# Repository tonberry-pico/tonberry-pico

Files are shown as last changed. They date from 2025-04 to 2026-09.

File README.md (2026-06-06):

# TonBERRY pico

Von [TonUINO](https://www.voss.earth/tonuino/) inspiriert, auf einer moderneren Platform für
zusätzliches Features: WLAN und Bluetooth zum Managen der Audiodateien per Handy-App oder Webseite -
kein Ausbau der SD-Karte mehr nötig. Aus Sicht des Hörers bleibt die Funktionalität aber die selbe -
durch einfaches Auflegen einer RFID-Karte (oder einer Figur mit RFID-Chip) und wenige Tasten zur
Lautstärkeregelung kann das Gerät kinderleicht bedient werden.

Dabei soll der Geist des Ursprungsprojekts, dass es ein "einfach" zu bastelndes Projekt auch für
Elektronik- und Programmier-Unerfahrene ist erhalten bleiben.  Deswegen:
 - Zusammenbau aus fertigen Modulen, die mittels 2.54mm-Raster Sockel/Steckleisten zusammengesetzt
   werden - keine SMD-Lötarbeiten
 - Die Software ist größtenteils (bis auf kritische Module wie z.B. den MP3-Dekoder) in MicroPython
   geschrieben, sodass Anpassungen auch ohne weitergehende Programmierkenntnisse möglich sind
 - Die Kombination aus Raspberry Pi Pico W und sonstigen nötigen Modulen sollte nicht nennenswert
   teurer sein als die Arduino-Module des TonUNIO.

## Anleitung

[Aufbau- und Bedienungsanleitung](https://tonberry-pico.github.io/tonberry-pico/doc/MANUAL.de.html)

### Benötigte Hardware

| Bezeichnung | Berrybase- oder Reichelt-Link |
| --- | --- |
| RFID-RC522 | <https://www.berrybase.de/rfid-lesegeraet-mit-spi-schnittstelle-inkl.-karte-dongle> oder andere RC522 Module (ggf. Pinout beachten) |
| SparkFun microSD Transflash Breakout | [~~https://www.berrybase.de/sparkfun-microsd-transflash-breakout~~](https://www.berrybase.de/sparkfun-microsd-transflash-breakout) Leider nicht mehr verfügbar. [Hier](https://git.ka.blankertz.org/TonBERRY/sparkfun_microSD_Transflash_Breakout) ist das Layout in EAGLE und KiCad zum nachmachen lassen. |
| SparkFun MAX98357A | <https://www.berrybase.de/sparkfun-i2s-audio-breakout-max98357a> oder <https://www.berrybase.de/adafruit-i2s-3w-class-d-verstaerker-breakout-max98357a> oder <https://www.amazon.de/dp/B0F21T7Q3P> |
| Raspberry Pi Pico W | <https://www.berrybase.de/raspberry-pi-pico-w-rp2040-wlan-mikrocontroller-board> |
| Adafruit bq25185 Ladegerät/Spannungswandler für Akkus ab 500mAh, JST PH-2 Pin, USB/DC/Solar, 5V, 1A | <ul><li><https://www.berrybase.de/adafruit-bq25185-ladegeraet-spannungswandler-fuer-akkus-ab-500mah-jst-ph-2-pin-usb-dc-solar-5v-1a></li><li><https://www.kiwi-electronics.com/en/adafruit-bq25185-usb-dc-solar-charger-with-5v-boost-board-20429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></li></ul> |
| Übrige Komponenten | <https://www.reichelt.de/my/2314794> |

### Software

Die Software ist [auf Github](https://github.com/tonberry-pico/tonberry-pico) zu finden.

### Gehäuse

Test-Aufbau für Entwickler: <https://www.printables.com/model/1745596-tonberry-pico-test-rig>

## Design

[Überlegungen zum Design](https://github.com/tonberry-pico/tonberry-pico/wiki/Design) gibt's im Wiki.

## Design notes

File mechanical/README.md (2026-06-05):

# Tonberry pico cases

## Test rig

The test rig consists of three parts:

The front plate holds the speaker. The mounting holes are for either a Visaton R10 S (or similiar)
speaker, or a small mono speaker https://www.adafruit.com/product/3351 .

The base plate is available in two versions: For the Rev. 1 PCB (the larger PCB with the buttons
mounted directly on the PCB, deprecated), and the Rev. 1.2 PCB plus an optional button board.

The RC522 holder clips onto the top and holds the RC522 NFC reader so that a tag or card can easily
be placed on it.

Besides the 3D printed parts, you need some hardware:

* M3x5x4 heat sink inserts: 8 for the Rev.1 PCB or if you aren't using a button board with the Rev. 1.2, or 12 for a Rev. 1.2 PCB plus button board. 
* M3x6 BHCS (button head) screws to mount the PCB(s): 4 or 8
* M3x8 countersunk screws: 4, to mount the front plate to the base
* M3x12 countersunk screws + M3 nuts: 4, to mount the RC522 to the holder
* For the Visaton speaker: 4x M4x8 countersunk screws + 4x M4 nuts
* For the ADA3351 speaker: 4x M3x? countersunk screws + 4x M3 nuts

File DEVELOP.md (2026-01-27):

# Developer notes

## How to setup python environment for mypy and pytest

```bash
cd software
python -m venv test-venv
. test-venv/bin/activate
pip install -r tests/requirements.txt
pip install -U micropython-rp2-pico_w-stubs --target typings
```

## 'database' schema for btree db

### Playlist storage

The playlist data is stored in the btree database in a hierarchical schema. The hierarchy levels are
separated by the '/' character.  Currently, the schema is as follows: The top level for a playlist
is the 'tag' id encoded as a hexadecimal string. Beneath this, the 'playlist' key contains the
elements in the playlist. The keys used for the playlist entries must be decimal integers,
left-padded with zeros so their length is 5 (e.g. format `{:05}`).

#### Playlist modes

The 'playlistshuffle' key located under the 'tag' key can be 'no' or 'yes' and specifies whether the
playlist is in shuffle mode. Should this key be absent the default value is 'no'.

The 'playlistpersist' key located under the 'tag' key can be 'no', 'track' or 'offset'. Should this
key be absent the default value is 'track'.

 * When it is 'no', the playlist position is not saved when playback stops. If shuffle mode is
   active, the shuffle random seed is also not saved.
 * When it is 'track', the currently playing track is saved when playback stops. If shuffle mode is
   active, the shuffle random seed is also saved. Should playback reach the last track (in shuffle
   mode: the last track in the permutated order), the saved position is reset and playback is
   stopped. The next time the playlist is started it will start from the first track and with a new
   shuffle seed if applicable.
 * When it is 'offset', the operation is basically the same as in 'track' mode. The difference is
   that the offset in the currently playing track is also saved and playback will resume at that
   position.

The 'playlistpos' key located under the 'tag' key stores the key of the current playlist
entry. The 'playlistshuffleseed' key stores the random seed used to shuffle the playlist.
The 'playlistposoffset' key stores the offset in the current playlist entry.

#### Example

For example, a playlist with two entries 'a.mp3' and 'b.mp3' for a tag with the id '00aa11bb22'
would be stored in the following key/value pairs in the btree db:

 * 00aa11bb22/playlist/00000: a.mp3
 * 00aa11bb22/playlist/00001: b.mp3
 * 00aa11bb22/playlistpos: 00000

## Notes for UI development with chromium

Features for the web interface are best prototyped in a browser directly. By using the built-in developmer tools and
and their "override" feature, the web contents are replaced by a locally stored copy, which can be used to directly
test the modifications without going all the way through the build and flash process.

However, modern browsers may restrict or even completely forbid the execution of dynamic content like JavaScript, if
the content is stored on the local machine and/or the content is accessed using http. In such a case, chromium issues
an error message similar to the following one:

> Access to fetch at 'http://192.168.4.1/api/v1/audiofiles' from origin 'http://192.168.4.1' has been blocked by CORS
> policy: The request client is not a secure context and the resource is in more-private address space `local`.

To mitigate this, chromium offers two flags that need modification:
- 'chrome://flags/#local-network-access-check' must be `Disabled`
- 'chrome://flags/#unsafely-treat-insecure-origin-as-secure' must be `Enabled`

Note that these settings leave the browser susceptible to security issues and should be returned to
their default values as soon as possible.

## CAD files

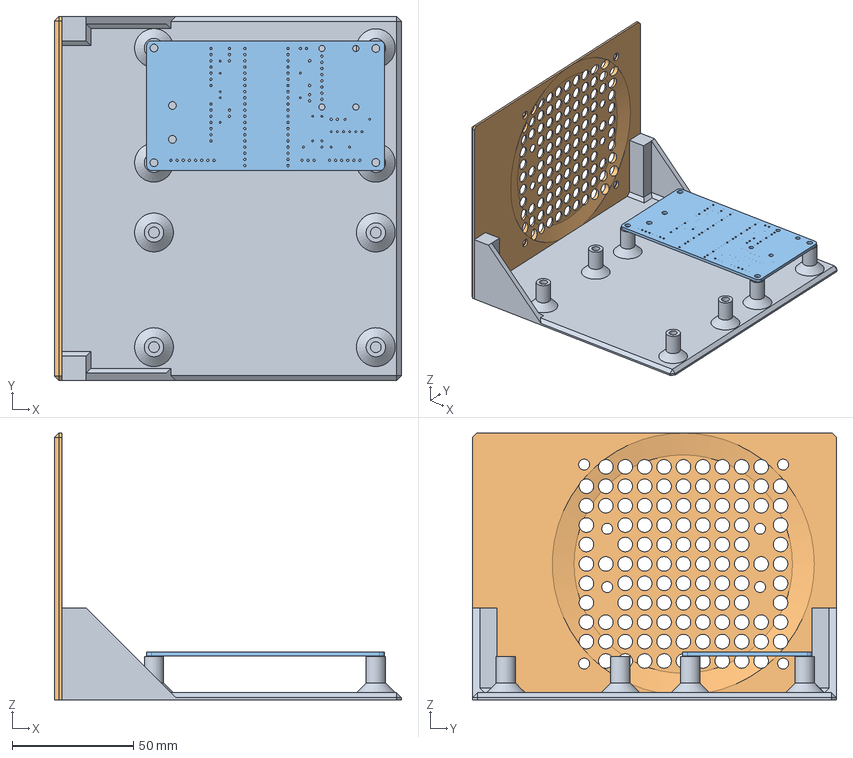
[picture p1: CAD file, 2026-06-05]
mechanical/test-rig-pcbv1.2.FCStd
143.0 x 150.0 x 110.0 mm
tonberry-pico_PCB001

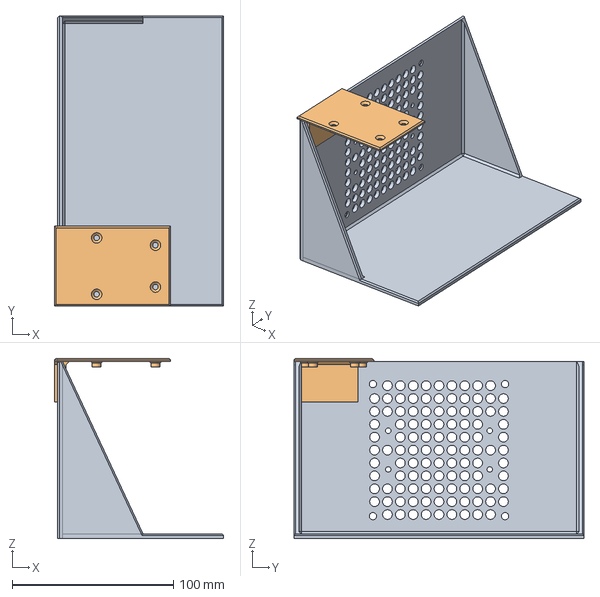
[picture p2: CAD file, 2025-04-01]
mechanical/test-rig.FCStd
105.1 x 180.0 x 112.0 mm

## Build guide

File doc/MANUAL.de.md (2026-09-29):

# TonBERRY pico - Aufbau- und Bedienungsanleitung

## Aufbau

Allgemeine Hinweise zum Aufbau:

* Das "interactive BOM" [hier](assets/ibom_rev1.2.html) gibt eine Übersicht darüber, wo welche
  Bauteile bestückt werden sollen

* Am besten erst die Einzelkomponenten (Widerstände, Kondensatoren, Dioden, Transistoren, Jumper)
  der (Bauteil-)Höhe nach sortiert von klein zu groß bestücken, dann können die Teile durch Auflegen
  auf eine Unterlage oder Einklemmen fixiert werden. Danach die Module bestücken.

* Wenn kein Akkubetrieb gewünscht ist, müssen die folgenden Bauteile nicht bestückt werden:
  * Adafruit Modul J4
  * Widerstände R1 und R3-5
  * Transistoren Q1 und Q2
  * Dioden D2 und D3
  * Jumper JP1, JP2 und JP4

* Der Widerstand R2 kann genutzt werden, um den Verstärkungsfaktor des Verstärkers grob
  einzustellen. Der Verstärkungsfaktor hängt dabei vom Widerstandswert und der Verbindung ab, für
  R2 sind zwei verschiedene Bestückungspositionen vorgesehen. Es gibt die folgenden Stufen:
  * 100 kΩ nach 5V: 3 dB (empfohlener Standardwert)
  * 0 Ω nach 5V: 6 dB
  * nicht verbunden: 9 dB
  * 0 Ω nach GND: 12 dB
  * 100 kΩ nach GND: 15 dB

* Der Reset-Taster SW5 muss nur bestückt werden, wenn man das Gerät benutzten will, um selbst an der
  Software zu entwickeln.

* Die "primäre" USB-Buchse ist der micro-USB Anschluss des Raspberry Pi Pico W. Der USB-Anschluss
  auf dem BQ25185-Modul kann zwar genutzt werden, um das Gerät mit Strom zu versorgen. Es ist aber
  ohne Weiteres keine Datenverbindung möglich, um die Software zu installieren.

### Pinbelegung der Steckverbinder

#### RC522 (J3)

Pin 1 ist links, wenn die Platinenbeschriftung normal lesbar ist. Vorsicht, hier hat sich in Hardware Version Rev 1.2 ein Fehler eingeschlichen: die Pin-1-Markierung auf der Platine (Silkscreen) ist leider auf dem falschen Pin.

| Pin | Belegung  |
|-----|---|
| 1 | VCC |
| 2 | RST |
| 3 | GND |
| 4 | IRQ |
| 5 | MISO |
| 6 | MOSI |
| 7 | SCK |
| 8 | SDA (=SS) |

Diese Belegung *sollte* 1:1 der Belegung des
[RFID-RC522 Moduls](https://www.berrybase.de/rfid-lesegeraet-mit-spi-schnittstelle-inkl.-karte-dongle)
entsprechen. Die Belegung des RC522-Moduls kann sich allerdings bei einzelnen Varianten unterscheiden, daher bitte immer überprüfen.

#### LED WS2812 (J6)

| Pin | Belegung |
|-----|---|
| 1 | 5V |
| 2 | Data |
| 3 | GND |

#### Buttons (J7)

| Pin | Belegung |
|-----|---|
| 1 | GND |
| 2 | Power/Button 4 (GP21) |
| 3 | Button 2 (GP19) |
| 4 | Button 1 (GP18) |
| 5 | Button 0 (GP17) |
| 6 | Button 3 (GP20) |

#### Akku (an J4)

Bei gewünschtem Akkubetrieb muss neben den oben beschriebenen Komponenten auch ein geeigneter Akku ausgewählt werden.
Das [Ladereglermodul](https://www.adafruit.com/product/6106) unterstützt folgende Akkutypen:

* Lithium-Ionen (Li-ion)
* Lithium-Polymer (Li-po)
* Lithium-Eisenphosphat (LiFePO4) (Achtung: Ladeschlussspannung ist fix auf 4,2 V eingestellt)

Der Akku wird am Ladereglermodul wie dargestellt angeschlossen:
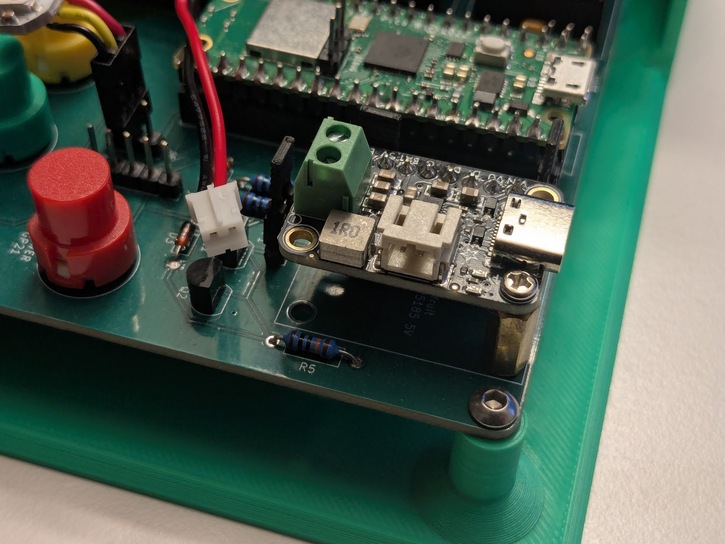
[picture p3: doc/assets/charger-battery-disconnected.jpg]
charger-battery-disconnected Ladereglermodul von Akku getrennt

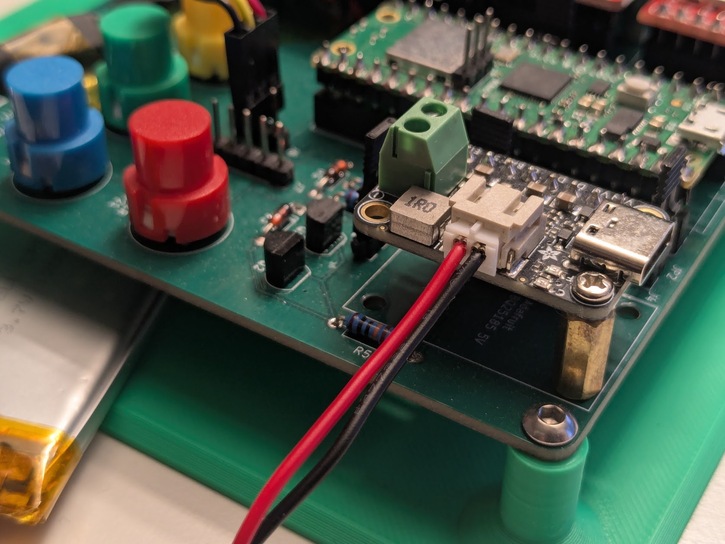
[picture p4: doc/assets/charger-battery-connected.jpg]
charger-battery-connected Ladereglermodul und Akku verbunden


Gut geeignet sind Akkus, die bereits einen fertig vorkonfektionierten Stecker vom Typ JST-PH (2 Pin)
haben, da diese direkt am Modul angesteckt werden können. Bewährt haben sich LiPo-Akkus mit einer
Ausgangsspannung von 3,7 V und einer Kapazität von 1200 oder 2500 mAh. Bei Berrybase aktuell gut
verfügbare Modelle sind der [503759 (1200 mAh)](https://www.berrybase.de/soldered-li-ion-akku-lithium-polymer-503759-3-7v-1200mah-mit-2-pin-jst-stecker)
oder der [LP-785060 (2500 mAh)](https://www.berrybase.de/lp-785060-lithium-polymer-lipo-akku-3-7v-2500mah-mit-2-pin-jst-stecker).
Je nach Bedarf können auch Akkus mit einer kleineren oder größeren Kapazität verwendet werden.

> [!IMPORTANT]
>
> Das Ladereglermodul verfügt über eine Schutzfunktion, die den Ladevorgang nach einer maximalen
> Ladezeit von 720 Minuten automatisch beendet. Während des Ladevorgangs gibt das Modul (im
> Auslieferungszustand) einen maximalen Ladestrom von 1 A an den Akku ab.
>
> Berücksichtigt man nun die Nichtlinearität des Ladevorgangs sowie die thermische Verlustleistung
> beim Laden, so ergibt sich eine maximale, realistische Akkukapazität von etwa 10.000 mAh.
>
> Es ist also nicht sinnvoll, einen Akku mit einer größeren Kapazität zu verwenden, da dieser niemals
> vollständig geladen werden wird.

> [!NOTE]
>
> Wir haben noch keine Messungen bezüglich der zu erwartenden Batterielaufzeit. Dies ist ein
> offenes TODO und wird später nachgereicht.

#### Lautsprecher (an J2)

Die Wahl eines geeigneten Lautsprechers hängt sehr von der Bauform der Box ab, weshalb allgemeingültige
Empfehlungen schwierig sind. Grundsätzlich sollte der verwendete Lautsprecher jedoch die folgenden
technischen Eigenschaften haben:

* Eingangsimpedanz: 8 Ohm (empfohlen)
  Eine niedrigere Impedanz (z.B. 4 Ohm) führt zu höherer Maximallautstärke und größerer Belastung des Verstärkers.
  Eine höhere Impedanz (z.B. 16 Ohm) hat den gegenteiligen Effekt.
* Nennleistung: 20 W (empfohlen)

Folgende Modelle wurden getestet:

* [Visaton R 10 S - 8 Ohm](https://www.reichelt.de/de/de/shop/produkt/breitbandlautsprecher_r_10s_20_w_8_ohm-22417)
  Gute Tonqualität, gute Sprachverständlichkeit auch bei niedrigen und hohen Lautstärken
* [Waveshare 8 Ohm 5 W](https://www.berrybase.de/8-ohm-5w-lautsprecher-passend-fuer-waveshare-displays)
  Für Tests geeignet

Der verwendete Lautsprecher wird am Verstärkermodul J2 angeschlossen. Die Kabel können entweder direkt auf das
Verstärkermodul aufgelötet werden, es kann aber auch ein Stecker mit Rastermaß 2,54 mm verwendet werden:

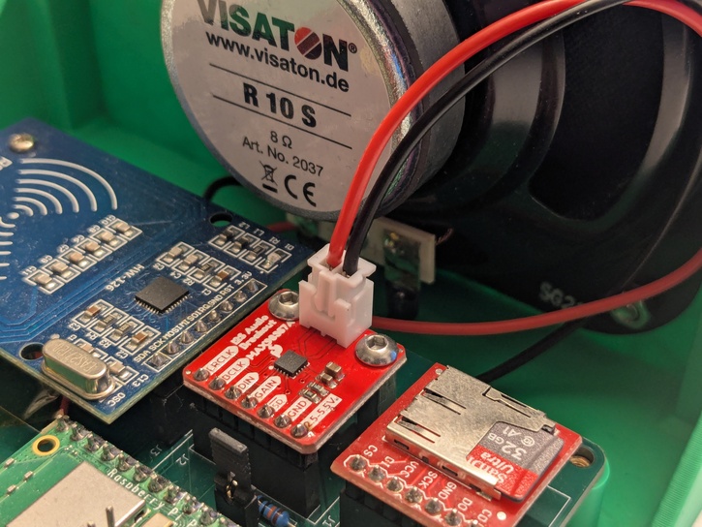
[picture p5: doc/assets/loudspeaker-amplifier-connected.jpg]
loudspeaker-amplifier-connected Lautsprecher, mit Steckverbinder angeschlossen


## Inbetriebnahme

### Softwareinstallation

Eine microSD-Karte mit FAT32 Dateisystem formatieren und in den microSD Slot einsetzen. Es können
bereits MP3-Dateien auf die SD-Karte kopiert werden. Die Karte sollte aber nicht komplett voll sein,
da eine interne Playlist-Datenbank ebenfalls auf der SD-Karte abgelegt wird und ggf. über die Zeit
größer werden wird. Empfohlen wird, etwa 10 MB frei zu lassen.

Zur Erstinstallation die Firmware `firmware-filesystem-Rev1.uf2` auf den Raspberry Pi Pico W
installieren. Dazu die "BOOTSEL"-Taste auf dem Pi Pico gedrückt halten und währenddessen das Gerät
über die Micro-USB Buchse auf dem Pi Pico mit dem PC verbinden. Es sollte dann ein USB-Laufwerk
auftauchen. Die "BOOTSEL"-Taste kann nun losgelassen werden. Dann die Datei
`firmware-filesystem-Rev1.uf2` auf das USB-Laufwerk kopieren.

> [!IMPORTANT]
>
> Für spätere Softwareaktualisierungen sollte die Datei `firmware-Rev1.uf2` benutzt werden, um die
> auf dem Gerät gespeicherte Konfiguration zu behalten. Mit der Datei `firmware-filesystem-Rev1.uf2`
> wird die gespeicherte Konfiguration überschrieben und in den Initialzustand zurückgesetzt. Dies
> betrifft u.a. die Anmeldeinformationen für ein WiFi, falls diese gesetzt wurden.

### Konfiguration

Es gibt zwei Speicherorte auf dem Gerät. Auf der SD-Karte wird die Datenbank abgelegt, in welcher die
Playlisten und die Zuordnung von NFC-Tags zu Playlisten gespeichert sind.

Auf dem Pi Pico selbst wird die Systemkonfiguration gespeichert. Hier werden die Informationen zum
WLAN-Zugang, zur Tastenbelegung und weitere Konfigurationsdaten gespeichert. 

Somit bleibt einerseits die Systemkonfigurationsdaten auf dem Gerät erhalten, selbst wenn die
SD-Karte getauscht wird. Andererseits wandern die Playlisten und Tags mit der SD-Karte mit, wenn
z.B. die SD-Karte in ein anderes Gerät eingesetzt wird.

Nach der Erstinstallation öffnet das Gerät einen WLAN-Accesspoint mit der SSID
"TonberryPicoAP_abcdef0123456789" auf, wobei der Teil "abcdef0123456789" individuell von der
Seriennummer des Pi Pico abhängig ist. Nach einer Verbindung mit diesem AP kann die Seite
<http://192.168.4.1> aufgerufen werden. Die Startseite des Webinterfaces wird angezeigt:

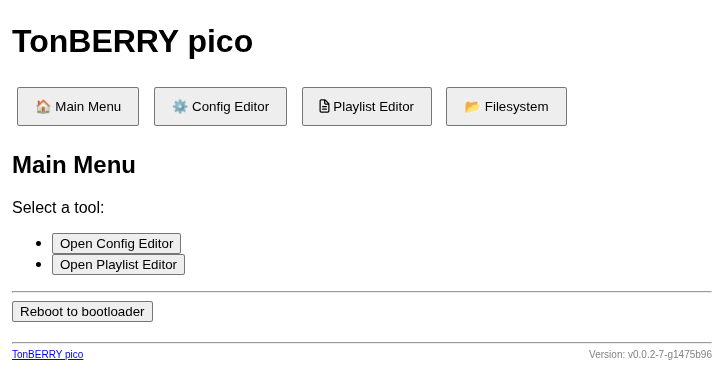
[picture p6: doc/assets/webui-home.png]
webui-home Startseite


Durch Klicken auf die "Config Editor" Schaltfläche gelangt man zum "Configuration Editor". Hier kann
die Systemkonfiguration editiert werden.

#### Button map

Es können bis zu 5 Taster an das Gerät angeschlossen werden. Die Funktion der Tasten ist, bis auf
das Einschalten, frei konfigurierbar. Eingeschaltet wird das Gerät immer über die Taste, die an
"GP21" angeschlossen ist (Pin 2 von J7).

In der Konfiguration werden die Tasten durch Ziffern von 0 bis 4 identifiziert. Die Zuordnung auf
der Rev. 1.2-Platine ist wie folgt:

| Button map  | GPIO Pin  | J7 Pin |
|---|---|---|
| 0 | GP17 | 5 |
| 1 | GP18 | 4 |
| 2 | GP19 | 3 |
| 3 | GP20 | 6 |
| 4 | GP21 | 2 |

Jeder Taste sollte nur eine Funktion zugeordnet werden.

#### WLAN

Im Ausgangszustand strahlt der Tonberry Pico eine eigene SSID aus und bietet so ein
unverschlüsseltes WiFi an. Die SSID lautet `TonberryPicoAP_<UID>`. Der TonberryPico ist unter der
IP-Adresse 192.168.4.1 erreichbar und verteilt Adressen aus dem Subnetz 255.255.255.0 per
DHCP.

Da der Tonberry WLAN als primäre Konfigurations- und Upload-Schnittstelle nutzt, kann das WLAN nicht
abgeschaltet werden.

Um einem bestehenden WLAN beizutreten, den Netzwerknamen unter "Network name" eingeben. Das Passwort
in das Feld "Password" eingeben. Mit "Security mode" kann die Verschlüsselungsart des Netzwerks
eingestellt werden. Der TonberryPico bezieht eine IP-Adresse per DHCP. Der TonberryPico ist unter
<http://tonberrypico.local> per mDNS auflösbar.

Wenn der Tonberry einen eigenen WLAN-Accesspoint aufmachen soll, das Feld "Network name"
freilassen. Auch hier können über "Password" und "Security mode" das Passwort und die
Verschlüsselungsart eingestellt werden.

#### Sonstige Einstellungen

* **Tag removal timeout (seconds)** Wie lange es dauert, bis ein nicht mehr erkannter NFC-Tag als
  entfernt gilt. In Abhängigkeit von Tag, Abstand zum Leser und Umgebungsbedingungen kann es zu
  kurzzeitigen Aussetzern in der NFC-Kommunikation kommen. Mit dieser Einstellung kann man
  verhindern, dass die Musikwiedergabe in solchen Fällen ungewollt angehalten wird.

* **Tag mode**: Hier kann zwischen zwei Wiedergabemodi gewechselt werden:
  * **Play until tag is removed**: Die Musik spielt, solange der NFC-Tag vom Gerät erkannt wird. Wird der
    Tag (für mehr als "Tag removal timeout" Sekunden) entfernt, stoppt die Wiedergabe.
  * **Present tag once to start, present again to stop playback**: Die Musik fängt an zu spielen, wenn
    ein Tag erkannt wird. Der Tag muss nicht auf dem Gerät bleiben. Durch erneutes Vorhalten
    desselben Tags nach einer kurzen Wartezeit kann die Wiedergabe gestoppt werden. Beim Vorhalten
    eines anderen Tags wechselt die Wiedergabe auf die Playlist des neuen Tags.

* **Maximum LED brightness**: Helligkeit der WS2812 LEDs, 0 - 255.

* **Maximum volume**: Begrenzung der maximalen Lautstärke, 0 - 255.

> [!TIP]
> Die tatsächliche Lautstärke hängt von der Bestückung des Widerstands R2 (siehe [Aufbau](#Aufbau)) und
> der abgespielten MP3-Datei ab.

* **Volume at startup**: Initiale Lautstärke nach dem Einschalten, 0 - 255.

* **Idle timeout (seconds)**: Nur im Akkubetrieb: Wie lange das Gerät bei pausierter oder gestoppter
  Musikwiedergabe wartet, bevor es sich ausschaltet.

* **Length of WS2812 / Neopixel LED chain**: Wie viele RGB-LEDs hintereinander am LED-Anschluss
  angeschlossen sind.

#### Speichern

Durch Klicken auf "Save & Reboot" werden die Einstellungen gespeichert. Das Gerät startet dann neu,
um die Einstellungen anzuwenden. Danach muss man sich ggf. neu mit dem WLAN des Geräts verbinden.

Wenn man durch einen Fehler bei der WLAN-Konfiguration nicht mehr auf die Konfigurationsseite
zugreifen kann, gibt es im Abschnitt "Besondere Tastenkombinationen" Abhilfe.

## Benutzung

### Grundfunktionen

Das Gerät wird durch die Power-Taste (Akkubetrieb) oder durch Einstecken des USB-Kabels
eingeschaltet.

Nach dem Einschalten des Geräts leuchten die LEDs erst kurz Gelb ("Gerät startet"), und pulsieren
danach langsam grün ("Gerät bereit").

Durch Auflegen eines Tags, für den eine Playlist konfiguriert ist, kann die Musikwiedergabe
gestartet werden. Die LED(s) leuchten in einem Regenbogenmuster. Die Tasten "Vor" ("Next track") und
"Zurück" ("Previous track") erlauben zum vorherigen oder nächsten Track zu springen. Die Taste "Play/Pause"
pausiert die Musikwiedergabe oder nimmt sie wieder auf.

Mit den Tasten "lauter" ("Volume up") und "leiser" ("Volume down") kann die Lautstärke bis zur
konfigurierten Maximallautstärke verändert werden.

### Playlisten-Verwaltung

Im Webinterface kann durch Klicken auf "Playlist Editor" der Playlist-Editor geöffnet werden.

#### Anlegen einer Playlist

Entweder die Tag-ID eingeben, oder den Tag auf das Gerät legen und auf "Get last tag" klicken um die
Tag-ID des zuletzt aufgelegten Tags auszulesen. Danach auf "New playlist" klicken um eine neue
Playlist anzulegen. Die Webseite wechselt dann in den Dialog zum Bearbeiten der Playlist (siehe nächster
Abschnitt).

> [!WARNING]
> Wenn bereits eine Playlist für die Tag-ID existiert, wird diese überschrieben.

#### Bearbeiten einer Playlist

Durch Auswählen einer existierenden Playlist im "Playlists"-Feld und klicken auf "Edit playlist"
kann eine bestehende Playlist bearbeitet werden.

Im oberen Bereich kann jetzt der Wiedergabetyp "Playlist type" und der Name der Playlist eingestellt
werden.

Im unteren Bereich können die auf der SD-Karte gespeicherten MP3-Dateien zur Playlist hinzugefügt,
gelöscht oder neu angeordnet werden. Nach dem Klick auf "Add tracks" wechselt die Ansicht in eine
Dateisystemansicht. Hier können MP3-Dateien ausgewählt werden, um zur Playlist hinzugefügt zu
werden. Das Hochladen von neuen MP3-Dateien ist in dieser Ansicht auch möglich.

Die fertige Playlist muss mit einem Klick auf "Save" gespeichert werden.

### Besondere Tastenkombinationen

Zur Nummerierung der Tasten siehe [Button map](#button-map).

* Standard WLAN Konfiguration laden: Wenn beim Start die Taste 1 gehalten wird, blinken die LED(s)
  einmal blau. Das Gerät benutzt dann temporär die WLAN-Standardkonfiguration und macht einen
  offenen WLAN-Accesspoint mit dem Namen "TonberryPicoAP_abcdef0123456789" auf, wobei der Teil
  "abcdef0123456789" individuell von der Seriennummer des Pi Pico abhängig ist. Damit kann bei
  fehlerhafter WLAN-Konfiguration wieder auf die Konfigurationsseite zugegriffen werden, um die
  WLAN-Konfiguration zu korrigieren.
  
* Ausschalten: Durch langes Gedrückthalten der Taste "leiser" kann das Gerät ausgeschaltet (im
  Akkubetrieb) oder neu gestartet (im USB-Betrieb) werden.
  
* Entwicklermodus: Durch Gedrückthalten der Taste 0 beim Start wird der Start der Software
  unterbrochen (die LEDs leuchten rot). In diesem Modus kann, wenn das Gerät per USB verbunden ist,
  mit dem `mpremote`-Tool mit der MicroPython-Shell interagiert werden.

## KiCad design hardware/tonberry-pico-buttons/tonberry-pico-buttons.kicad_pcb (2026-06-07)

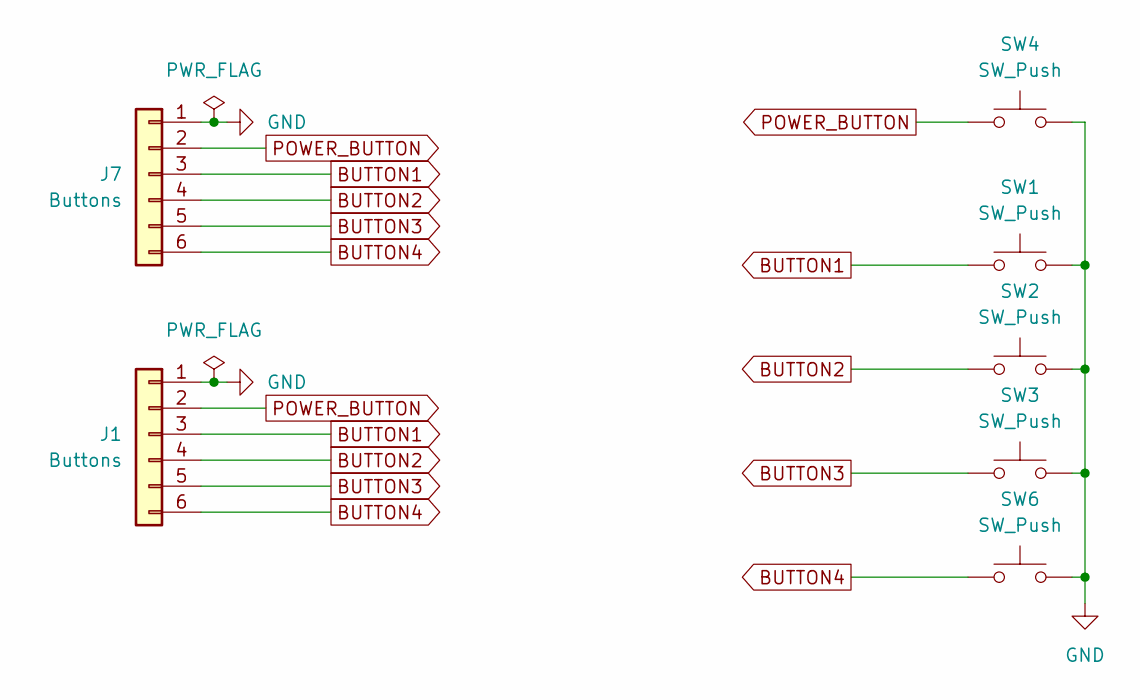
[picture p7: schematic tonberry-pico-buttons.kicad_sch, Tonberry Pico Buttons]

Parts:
J1, J7: Buttons; JST_XH_B6B-XH-A_1x06_P2.50mm_Vertical
SW1, SW2, SW3, SW4, SW6: SW_Push; Push_E-Switch_KS01Q01

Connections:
BUTTON1: J1.3, J7.3, SW1.1
BUTTON2: J1.4, J7.4, SW2.1
BUTTON3: J1.5, J7.5, SW3.1
BUTTON4: J1.6, J7.6, SW6.1
GND: J1.1, J7.1, SW1.2, SW2.2, SW3.2, SW4.2, SW6.2
POWER_BUTTON: J1.2, J7.2, SW4.1

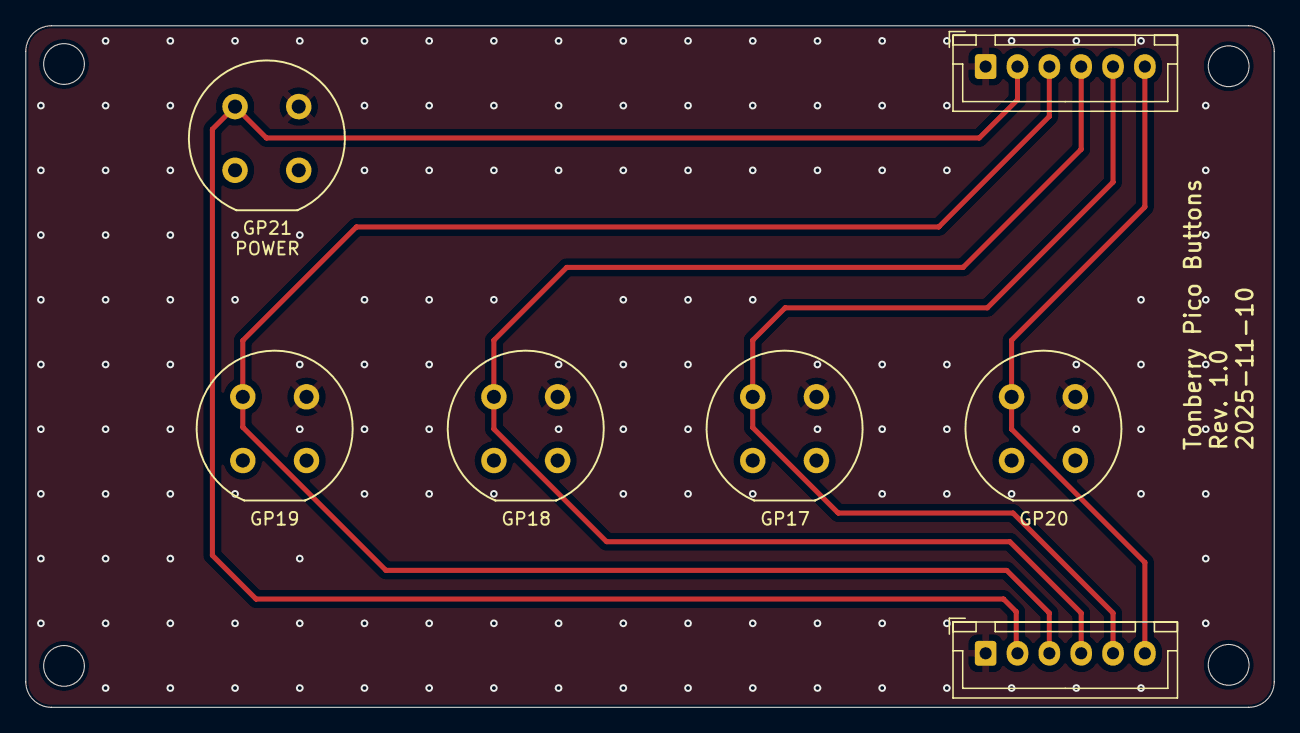
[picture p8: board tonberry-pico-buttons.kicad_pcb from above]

Board: 2 copper layers, 98.0 x 53.5 mm, 7 parts (0 on the bottom side), 6 nets.

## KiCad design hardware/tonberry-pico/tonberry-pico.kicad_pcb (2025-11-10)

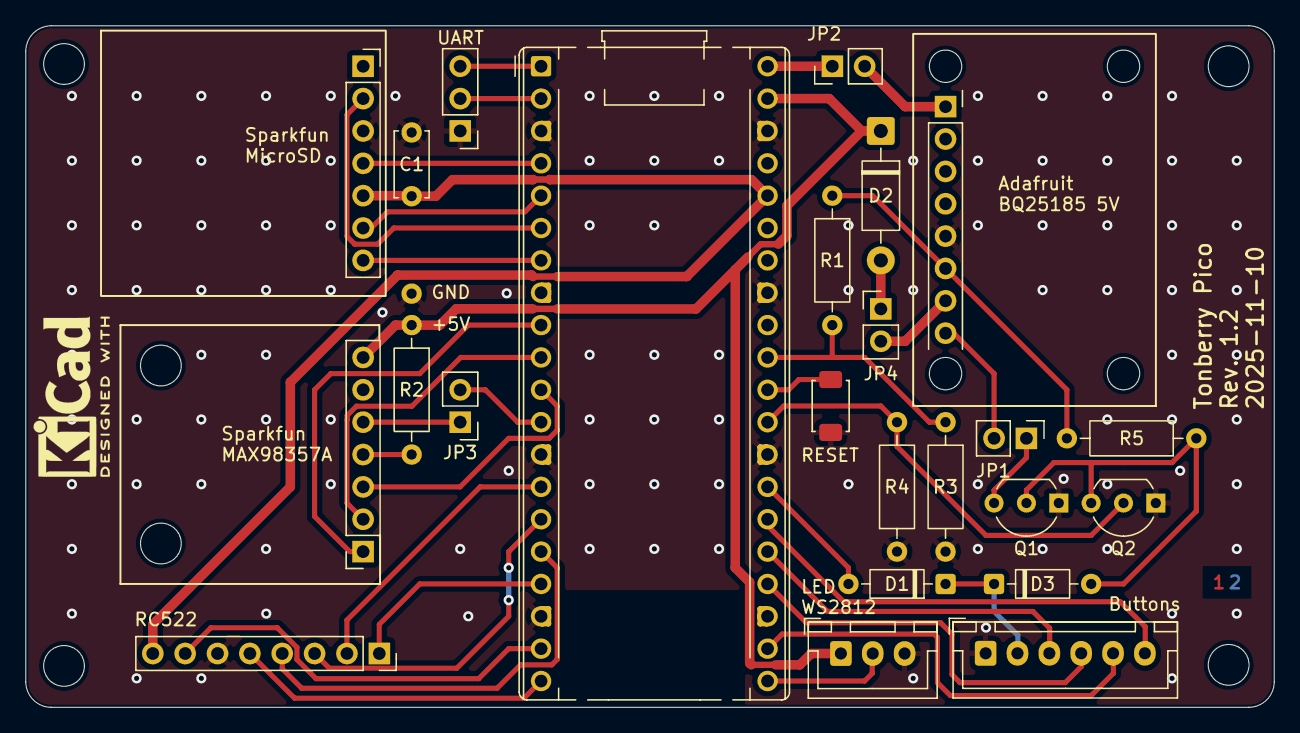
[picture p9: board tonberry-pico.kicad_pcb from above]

Board: 2 copper layers, 98.0 x 53.5 mm, 25 parts (0 on the bottom side), 39 nets.

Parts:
C1: 100 nF; C_Disc_D5.0mm_W2.5mm_P5.00mm
D1, D3: 1N4448; D_DO-35_SOD27_P7.62mm_Horizontal
D2: 1N5817; D_DO-41_SOD81_P10.16mm_Horizontal
J1: MicroSD_Breakout; Sparkfun_MicroSD_Breakout
J2: SparkFun I2S Audio Breakout MAX98357A; Sparkfun_MAX98357A
J3: RC522_Breakout; PinSocket_1x08_P2.54mm_Vertical
J4: Adafruit_bq25185_5V; Adafruit_bq25185
J5: UART; PinHeader_1x03_P2.54mm_Vertical
J6: WS2812; JST_XH_B3B-XH-A_1x03_P2.50mm_Vertical
J7: Buttons; JST_XH_B6B-XH-A_1x06_P2.50mm_Vertical
J8: Conn_01x01; SolderWire-0.25sqmm_1x01_D0.65mm_OD1.7mm
JP1, JP2, JP3, JP4: Jumper_2_Bridged; PinHeader_1x02_P2.54mm_Vertical
Q1, Q2: 2N7000; TO-92_Inline_Wide
R1, R2, R3, R4, R5: 100k; R_Axial_DIN0207_L6.3mm_D2.5mm_P10.16mm_Horizontal
SW5: SW_Push; SW_TS-1088-AR02016
U1: RaspberryPi_Pico_W; RaspberryPi_Pico_Common_THT

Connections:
+3V3: C1.1, J1.5, J3.8, U1.36 (3V3)
+5V: D2.1 (K), J2.7, J6.1, R2.1, U1.39 (VSYS)
/BQ_+5V: J4.7, JP4.2 (B)
/BQ_EN: J4.8, JP1.2 (B)
/BQ_VBAT: J4.6, R1.1, R5.2
/BQ_VIN: J4.1, JP2.2 (B)
/I2S_DCLK: J2.2, U1.10 (GPIO7)
/I2S_DIN: J2.3, U1.11 (GPIO8)
/I2S_GAIN: J2.4, R2.2
/I2S_LRCLK: J2.1, U1.9 (GPIO6)
/I2S_SD: J2.5, JP3.1 (A)
/RC522_IRQ: J3.5, U1.20 (GPIO15)
/RC522_MISO: J3.4, U1.16 (GPIO12)
/RC522_MOSI: J3.3, U1.15 (GPIO11)
/RC522_RST: J3.7, U1.19 (GPIO14)
/RC522_SCK: J3.2, U1.14 (GPIO10)
/RC522_SS: J3.1, U1.17 (GPIO13)
/SD_CS: J1.7, U1.7 (GPIO5)
/SD_DI: J1.6, U1.5 (GPIO3)
/SD_DO: J1.2, U1.6 (GPIO4)
/SD_SCK: J1.4, U1.4 (GPIO2)
BUTTON1: J7.3, U1.25 (GPIO19)
BUTTON2: J7.4, U1.24 (GPIO18)
BUTTON3: J7.5, U1.22 (GPIO17)
BUTTON4: J7.6, U1.26 (GPIO20)
GND: C1.2, J1.3, J2.6, J3.6, J4.5, J5.1, J6.3, J7.1, J8.1, Q1.1 (S), Q2.1 (S), R3.2, R4.1, SW5.1, U1.3 (GND), U1.8 (GND), U1.13 (GND), U1.18 (GND), U1.23 (GND), U1.28 (GND), U1.33 (AGND), U1.38 (GND)
unnamed: D1.2 (A), U1.27 (GPIO21)
unnamed: D2.2 (A), JP4.1 (A)
unnamed: D3.2 (A), Q1.2 (G), Q2.3 (D), R5.1
unnamed: J5.2, U1.2 (GPIO1)
unnamed: J5.3, U1.1 (GPIO0)
unnamed: J6.2, U1.21 (GPIO16)
unnamed: JP1.1 (A), Q1.3 (D)
unnamed: JP3.2 (B), U1.12 (GPIO9)
POWER_BUTTON: D1.1 (K), D3.1 (K), J7.2
POWER_EN_RP: Q2.2 (G), R4.2, U1.29 (GPIO22)
RP_RUN: SW5.2, U1.30 (RUN)
VBAT_DIV_2: R1.2, R3.1, U1.31 (GPIO26_ADC0)
VBUS: JP2.1 (A), U1.40 (VBUS)

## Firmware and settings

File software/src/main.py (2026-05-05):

# SPDX-License-Identifier: MIT
# Copyright (c) 2024-2025 Matthias Blankertz <matthias@blankertz.org>

import aiorepl  # type: ignore
import asyncio
import machine
import micropython
import network
import time
import ubinascii
import sys

# Own modules
import app
from audiocore import AudioContext
import frozen_frontend  # noqa: F401
from mfrc522 import MFRC522
from mp3player import MP3Player
from nfc import Nfc
from rp2_neopixel import NeoPixel
from utils import BTreeFileManager, Buttons, SDContext, TimerManager, LedManager, Configuration
from webserver import start_webserver

try:
    import hwconfig
except ImportError:
    print("Fatal: No hwconfig.py found")
    raise

micropython.alloc_emergency_exception_buf(100)

# Machine setup
hwconfig.board_init()

# high prio for proc 1
machine.mem32[0x40030000 + 0x00] = 0x10


def setup_wifi(ssid='', passphrase='', security=network.WLAN.SEC_WPA_WPA2):
    network.hostname("TonberryPico")
    if ssid is None or ssid == '':
        apname = f"TonberryPicoAP_{machine.unique_id().hex()}"
        print(f"Create AP {apname}")
        wlan = network.WLAN(network.WLAN.IF_AP)
        wlan.config(ssid=apname, password=passphrase if passphrase is not None else '', security=security)
        wlan.active(True)
    else:
        print(f"Connect to SSID {ssid} with passphrase {passphrase}...")
        wlan = network.WLAN()
        wlan.active(True)
        wlan.connect(ssid, passphrase if passphrase is not None else '', security=security)

    # configure power management
    wlan.config(pm=network.WLAN.PM_PERFORMANCE)

    mac = ubinascii.hexlify(network.WLAN().config('mac'), ':').decode()
    print(f"     mac: {mac}")
    print(f" channel: {wlan.config('channel')}")
    print(f"   essid: {wlan.config('essid')}")
    print(f" txpower: {wlan.config('txpower')}")
    print(f"ifconfig: {wlan.ifconfig()}")


async def wdt_task(wdt):
    # TODO: more checking of app health
    # Right now this only protects against the asyncio executor crashing completely
    while True:
        await asyncio.sleep_ms(100)
        wdt.feed()

DB_PATH = '/sd/tonberry.db'

config = Configuration()

# Setup LEDs
np = NeoPixel(hwconfig.LED_DIN, config.get_led_count(), sm=1)
led_max = config.get_led_max()
np.fill((led_max, led_max, 0))
np.write()


def run():
    asyncio.new_event_loop()

    if machine.Pin(hwconfig.BUTTONS[1], machine.Pin.IN, machine.Pin.PULL_UP).value() == 0:
        np.fill((0, 0, led_max))
        np.write()
        # Force default access point
        setup_wifi('', '', network.WLAN.SEC_OPEN)
    else:
        wifi_passphrase = config.get_wifi_passphrase()
        secstring = config.get_wifi_security()
        security = network.WLAN.SEC_WPA_WPA2
        if secstring == 'open':
            security = network.WLAN.SEC_OPEN
        elif secstring == 'wpa_wpa2':
            security = network.WLAN.SEC_WPA_WPA2
        elif secstring == 'wpa3':
            security = network.WLAN.SEC_WPA3
        elif secstring == 'wpa2_wpa3':
            security = network.WLAN.SEC_WPA2_WPA3
        if wifi_passphrase is None or wifi_passphrase == '':
            security = network.WLAN.SEC_OPEN
            print("WiFi password not set, disabling WiFi security")
        setup_wifi(config.get_wifi_ssid(), wifi_passphrase, security)

    # Setup MP3 player
    with SDContext(mosi=hwconfig.SD_DI, miso=hwconfig.SD_DO, sck=hwconfig.SD_SCK, ss=hwconfig.SD_CS,
                   baudrate=hwconfig.SD_CLOCKRATE):
        with BTreeFileManager(DB_PATH) as playlistdb, \
             AudioContext(hwconfig.I2S_DIN, hwconfig.I2S_DCLK, hwconfig.I2S_LRCLK) as audioctx:

            # Setup NFC
            reader = MFRC522(spi_id=hwconfig.RC522_SPIID, sck=hwconfig.RC522_SCK, miso=hwconfig.RC522_MISO,
                             mosi=hwconfig.RC522_MOSI, cs=hwconfig.RC522_SS, rst=hwconfig.RC522_RST, tocard_retries=20)

            # Setup app
            deps = app.Dependencies(mp3player=lambda the_app: MP3Player(audioctx, the_app),
                                    nfcreader=lambda the_app: Nfc(reader, the_app),
                                    buttons=lambda the_app: Buttons(the_app, config, hwconfig),
                                    playlistdb=lambda _: playlistdb,
                                    hwconfig=lambda _: hwconfig,
                                    leds=lambda _: LedManager(np, config),
                                    config=lambda _: config)
            the_app = app.PlayerApp(deps)

            start_webserver(config, the_app)
            # Start
            wdt = machine.WDT(timeout=2000)
            asyncio.create_task(aiorepl.task({'timer_manager': TimerManager(),
                                              'app': the_app}))
            asyncio.create_task(wdt_task(wdt))
            asyncio.get_event_loop().run_forever()


def error_blink():
    while True:
        if machine.Pin(hwconfig.BUTTONS[0], machine.Pin.IN, machine.Pin.PULL_UP).value() == 0:
            machine.reset()
        np.fill((led_max, 0, 0))
        np.write()
        time.sleep_ms(500)
        np.fill((0, 0, 0))
        np.write()
        time.sleep_ms(500)


if __name__ == '__main__':
    time.sleep(1)
    if machine.Pin(hwconfig.BUTTONS[0], machine.Pin.IN, machine.Pin.PULL_UP).value() != 0:
        try:
            run()
        except Exception as ex:
            sys.print_exception(ex)
            error_blink()
    else:
        np.fill((led_max, 0, 0))
        np.write()

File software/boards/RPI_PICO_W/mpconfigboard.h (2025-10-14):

// Board and hardware specific configuration
#define MICROPY_HW_BOARD_NAME "Raspberry Pi Pico W"

// todo: We need something to check our binary size
#define MICROPY_HW_FLASH_STORAGE_BYTES (848 * 1024)

// Enable networking.
#define MICROPY_PY_NETWORK 1
#define MICROPY_PY_NETWORK_HOSTNAME_DEFAULT "PicoW"

// CYW43 driver configuration.
#define CYW43_USE_SPI (1)
#define CYW43_LWIP (1)
#define CYW43_GPIO (1)
#define CYW43_SPI_PIO (1)

// For debugging mbedtls - also set
// Debug level (0-4) 1=warning, 2=info, 3=debug, 4=verbose
// #define MODUSSL_MBEDTLS_DEBUG_LEVEL 1

#define MICROPY_HW_PIN_EXT_COUNT CYW43_WL_GPIO_COUNT

// If this returns true for a pin then its irq will not be disabled on a soft reboot
int mp_hal_is_pin_reserved(int n);
#define MICROPY_HW_PIN_RESERVED(i) mp_hal_is_pin_reserved(i)

#define MICROPY_PY_THREAD (0)

#define TONBERRY_POWER_EN 22

#define MICROPY_BOARD_STARTUP()                \
    {                                          \
        gpio_init(TONBERRY_POWER_EN);          \
        gpio_set_dir(TONBERRY_POWER_EN, true); \
        gpio_put(TONBERRY_POWER_EN, true);     \
    }

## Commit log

2024-04-18 Add initial schematic
    [tonberry-pico.kicad_pcb, tonberry-pico.kicad_sch]
2024-04-30 Swap I2S LRCLK and DCLK for compatibility with micropython I2S
    [tonberry-pico.kicad_sch]
2024-05-31 schematic: Add WS2812 / Neopixel on GPIO16
    [tonberry-pico.kicad_sch]
2024-05-31 Add copy of PICO_W board with disabled threading
    [pins.csv]
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2024-05-31 micropython: Update to v1.23.0
    Unfortunately we still need a patch against upstream due to the thread
    disabled build not building cleanly. Upstreaming attempt here:
    https://github.com/micropython/micropython/pull/15179
2024-06-02 Add audiocore module and I2S audio driver
    This is the skeleton of the code that will run on core1 to perform the
    audio decoding and output. In this initial commit, the module
    infrastructure, starting code on core1, and the I2S audio driver with
    DMA are implemented.
2025-01-28 Fixed uid output. Also fixed line endings (sorry).
    [main.py]
2025-01-28 microdot: First working example. We observe wifi instabilities/detectability issues.
    [main.py]
2025-03-10 Add rp2 PIO and DMA fast SD card driver
    The builtin micropython SD card driver using the default micropython SPI
    implementation suffered from very low read speeds. Add an optimized SD
    card driver using rp2 PIO and DMA. Currently read only, write support to
    be added later.
2025-03-10 rp2_sd: Cleanup and fixes
    - Use SD_SECTOR_SIZE define instead of magic number 512
    - Replace uint8_t buf[1] with plain uint8_t
    - Check sd_spi_read_dma precondition that sd_dma_context state has to be
    DMA_IDLE explicitly and return false instead of relying on assert
    - sd_spi_dma_isr is time critical
    [module.c, sd_spi.c]
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2025-03-22 audiocore: Add async support
    Rename the exising audiocore C module to _audiocore and create a new
    Micropython wrapper module audiocore. This makes it easier to implement
    async methods.
    Add interrupt support to _audiocore that notifies core0 whenever data
    has been consumed from the MP3 bitstream buffer.
    Use this interrupt and an asyncio.ThreadSafeFlag to implement
    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
2025-03-23 Fix crash when starting audiocore from REPL
    [module.c]
2025-04-01 Add test rig
    [test-rig.FCStd]
2025-04-01 schematic: Update to KiCad 9 and some minor fixes
    - Add gain setting resistor for I2S Amp
    - Add three pushbuttons
    [tonberry-pico.kicad_sch]
2025-05-20 Add basic application for playback based on NFC tags
    Copy and clean up test.py to main.py. Add app module (currently on
    app.py, maybe make it a directory later) for application classes.
    Implement app.TimerManager to allow scheduling of delayed events in the
    micropython async framework.
    Implement app.TagPlaybackManager which handles playing back MP3 files
    based on the NFC tag reader. Currently, simply plays all MP3 files in a
    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
2025-05-20 wip: New architecture
    Change PlayerApp to new architecture
    - depedencies injected via named tuple
    - some initial type checking
    - move on button press logic to PlayerApp
    TODO: Adapt MP3 player
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2025-07-22 rp2_sd: Add write support to SD driver
    Add write support to rp2_sd driver.
    Cleanup standalone-mp3 test tool and add write test mode.
2025-07-22 schematic: Fix I2S_SD pullup
    Sparkfun I2S audio board already has MAX98357A SD pin pullup for mono
    mode, so external pullup is redundant and can actually cause issues.
    Remove it.
    [tonberry-pico.kicad_sch]
2025-08-05 Handle partitioned and unpartitioned SD cards
    Add utils.MBRPartition to implement basic partitioned device support.
    Try to mount partition 1 of SDCard first, if that fails, try to mount
    entire device as FAT file system.
    [main.py, mbrpartition.py, sdcontext.py]
2025-08-20 audiocore: Fix small race window in get_fifo_read_value_blocking
    In theory, the FIFO interrupt could occur after getting the
    fifo_read_value and reenabling interrupts, but before __wfi is called,
    causing a deadlock. Fix this by calling __wfi with interrupts still
    disabled. It will return immediately if an interrupt is pending.
    Add two __nop to ensure that the CPU has enough instructions between
    enabling interrupts and disabling them again at the top of the loop.
    [module.c]
2025-08-24 micropython: upgrade to 1.26.0, reverted single commit.
    Migrated all patches from the previous version.
    A change in the Findpicotool.cmake script in the pico-sdk led to a
    downgrade of picotool, which incorporated mbedtls into the build, which
    itself is not buildable with cmake versions < 3.5.
    The commit which made this isolated change was reverted. Future versions
    of micropython will use pico-sdk 2.2.0 or newer, where this problem is
    fixed, and picotool is pinned to a release version.
    [module.c]
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2025-09-02 hw: Clean up schematic, add RUN reset
    Clean up schematic and put battery power, buttons and run/reset in
    subblocks.
    Add missing switch on RUN to reset the RP2040. In the PCB this is
    actually a jumper instead of a switch right now, so it fits in the
    existing layout.
    [tonberry-pico.kicad_pcb, tonberry-pico.kicad_sch]
2025-09-02 Add battery charger, PCB rev 1
    [tonberry-pico.kicad_pcb, tonberry-pico.kicad_sch]
2025-10-07 Make hardware configurable
    Move hardware-specifics (pin assignments, power management) to
    hwconfig_*.py.
    The build system will build a firmware image
    firmware-filesystem-$variant.uf2 for all variants for which a
    hwconfig_$variant.py file exits. Inside the filesystem image, the
    selected variants hwconfig_$variant.py file will always be named
    hwconfig.py.
    At runtime, main.py will attempt to import hwconfig which will load the
    configuration for the correct variant.
    Currently, the hwconfig_* modules are expected to define the pin mapping
    and implement a board_init method.
    [main.py, pinindex.py]
2025-10-07 audiocore: Support swapping dclk and lrclk pins for I2S
    [module.c]
2025-10-07 Add playlist database
    Add playlist database based on the micropython 'btree' module.
    Supported features are:
    * Create playlist
    * Load playlist
    * Store position in playlist
    Different playlist modes will be added in a followup for #24.
    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
2025-10-07 app: Fix bug when a tag that has no playlist is encountered
    [app.py]
2025-10-12 hw: Use new and improved RPi Pico symbol in schematic
    [tonberry-pico.kicad_pcb, tonberry-pico.kicad_sch]
2025-10-12 hw: Cleanup schematic style, fix ERC violations
    No netlist changes.
    [tonberry-pico.kicad_pcb, tonberry-pico.kicad_sch]
2025-10-13 board, hwconfig: Set POWER_EN in early boot
    In order to turn the Tonberry device on more reliably even if the power
    button is only pressed for a short time, move the setting of POWER_EN
    pin to high from the python board_init to the MICROPY_BOARD_STARTUP
    macro so that is is started in the C startup code run before the
    micropython interpreter is initialized.
    Measured time from power on to POWER_EN time was 600-800 ms with the
    python board_init, vs. 155 ms for the MICROPY_BOARD_STARTUP.
    [mpconfigboard.h]
2025-10-13 hwconfig: Fix pad config for SD SPI, move clockrate to hwconfig
    The code snippet in hwconfig to adjust the drive strength was incorrect:
    It was adjusting the wrong pins. This was probably not updated during
    some pin shuffling in the breadboard phase.
    Fix this by adjusting the correct pins. Experimentation shows that both
    setting the slew rate to fast or setting the drive strength to 8 mA
    (default: slow and 4 mA) is sufficient to make SD SPI work at 25 MHz on
    the Rev1 PCB. For now, the combination 8 mA and slow is chosen (slow
    slew rate should result in less high frequency EMI).
    Also make the SD clock rate adjustable in hwconfig, and set it to 25 MHz
    for Rev1 and 15 MHz for the breadboard s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
    [main.py]
2025-10-19 rp2_sd: Disable input synchronizer for MISO pin
    The PIO has an internal synchronizer on each GPIO input which adds two
    cycles of delay. This prevents metastabilities in the PIO logic (see
    RP2040 datasheet p. 374f). For high speed synchronous interfaces such as
    SPI this needs to be disabled to reduce input delay.
2025-10-19 rp2_sd: Improve error handling
    * In sd_cmd_read_complete, check read token and report appropriate error
    _before_ performing CRC check.
    * In sd_read_csd, correctly handle the sd_cmd_read() failing.
    * In sd_init, deinit the lower level sd_spi driver correctly on failure.
    [sd_spi.c]
2025-10-19 tools: standalone_mp3: Add read test, increase speed to 25 MHz
    Add a read test to the SD tests in standalone_mp3, and also apply the
    drive strength setup and higher clockrate from board_Rev1.py.
2025-10-27 rp2_sd: Fix race window in sd_spi_wait_complete
    Similar to the fix in 6f155ebb5516 ("audiocore: Fix small race window in
    get_fifo_read_value_blocking"), a race and deadlock is possible when
    calling __wfi with interrupts enabled. Fix it in sd_spi_wait_complete by
    copying the fix from the above commit.
    [sd_spi.c]
2025-10-27 audiocore: Fix race window in i2s_stop
    Apply the same pattern as in 6f155ebb5516 ("audiocore: Fix small race
    window in get_fifo_read_value_blocking") and 2a4033d3ca01 ("rp2_sd: Fix
    race window in sd_spi_wait_complete") to the wait for interrupt in
    i2s_stop too.
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2025-11-02 fix(main): Make upgrade from tag directories more ergonomical
    As we don't have an API to upload files and create playlists yet, we
    used the convention "tag uid as directory name" to allow testing
    playback. With the introduction of the database in #39 "Add playlist db"
    a builddb() function to initialize the database from the tag directories
    was added, but it is not automatically called. To make the developer
    experience more ergonomical, add a check for that automatically runs
    builddb() when no database exists.
    [main.py]
2025-11-07 hw: Add fifth button, make traces wider
    [tonberry-pico.kicad_pcb, tonberry-pico.kicad_sch]
2025-11-07 hw: Smaller 'production' version of board w/o keys and direct RC522 mount
    [tonberry-pico.kicad_pcb, tonberry-pico.kicad_sch]
2025-11-08 hw: Add GND point for MAX98357 gain config
    Add a through-hole pad connected to GND next to the MAX98357 gain config
    resistor to allow the user to select from all possible gains.
    [tonberry-pico.kicad_pcb, tonberry-pico.kicad_sch]
2025-11-09 fix(db): Fix type check in BTreeDB.getSetting
    Fix missing type() call in type check.
    Also remove leftover debug print().
    [playlistdb.py]
2025-11-10 hw: Update metadata, move silkscreen board name + rev
    No netlist or routing changes.
    [tonberry-pico.kicad_pcb, tonberry-pico.kicad_sch]
2025-11-10 hw: Final fixes for Rev 1.2
    - Move RC522 connector a bit further away from the MAX98375 module
    footprint, so a JST-XH connector can be used here too.
    - Update custom rules and fix some DRC warnings (no netlist and layout
    changes).
    [tonberry-pico.kicad_pcb, tonberry-pico.kicad_sch]
2025-11-11 feat: Change LED pattern based on playback state
    Move the LED control to the utils.LedManager class. For the first
    implementation, support two LED patterns 'idle' and 'playing'.
    Extend the PlayerApp to set the LED pattern based on playback state.
2025-11-11 feat: Implement shutdown on idle when on battery
    Allow the PlayerApp to turn off the device if it is idle for longer then
    the timeout. The timeout is currently hardcoded to 1 minute, this will be
    made configurable in the future.
2025-11-11 Forumlated potentially useful json schema.
    Note that this is based on an earlier state of the project, and the
    terms used in this schema may differ from the current state of the project.
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2025-11-28 style: Fix flake8 complaints
    Remove unused imports in main.py
    Add missing "global" in webserver and fix spacing.
    [main.py, webserver.py]
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2025-12-01 feat: Replace hardcoded timeouts in app with configurable
    [app.py, config.py, main.py]
2025-12-01 feat: Make button mapping configurable
    - Remove Pin to button mapping from hwconfig, replace with a simple list
    of Pins to which buttons are attached
    - Add BUTTON_MAP to config.json which maps indices in the HW button list
    to button names
    - Update utils.Buttons to use the button map to connect the correct pins
    to the matching key codes
    [buttons.py, config.py, hwconfig.py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]
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2025-12-01 fix: Ensure each timer can only be scheduled once
    If a timer is scheduled with the timer manager while it is already
    scheduled, the new exipry time should override the prev. expiry time
    instead of adding a second instance of the same timer function.
    [timer.py]
2025-12-03 fix: Block certain requests during playback
    Probably due to memory/stack overrun, some more involved web API
    requests cause the system to hang if performed during playback. For now,
    block these requests during playback.
    [app.py, main.py, webserver.py]
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2025-12-07 fix: exceptions in callback should not terminate caller
    [buttons.py, timer.py]
2025-12-07 fix: timer: handle modifications to timers when _timer_worker is already scheduled correctly
    [timer.py]
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2025-12-16 fix: config: Merge defaults into config at load time
    Merge defaults into config at load time to ensure that all config
    options show up in the configuration dialog, even if they were added
    after the local configuration was last changed.
    Also use the merge method to merge the local config with the new config
    in set_config, ensuring the config contains all keys even if the
    submitted config leaves some out.
    [config.py]
2025-12-16 feat: webserver: keep alive; move playback write prot to handler
    - Reset the app idle timer when interacting with the webapp, so that the
    device does not turn off while the web ui is used.
    - Handle denying put/post while playback is active centrally in the
    before_request handler, so that it does not need to be copy/pasted
    into every request handler.
    [app.py, webserver.py]
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2025-12-20 fix: webserver: Use streaming response for filesystem listing
    [webserver.py]
2025-12-20 fix: app: Go to idle mode when playlist end is reached
    [app.py]
2025-12-20 fix: Increase watchdog timeout
    Workaround for #60 until it is fixed.
    [main.py]
2025-12-21 feat: /api/v1/reboot/[bootloader|application], confirm with pink LED pattern
    [app.py, leds.py, webserver.py]
2025-12-21 feat: frontend: Add reboot to bootloader button (for updates)
2025-12-21 fix: fix flake8 complaint
    [app.py, webserver.py]
2025-12-21 feat: allow reboot commands only if usb cable is inserted
    [webserver.py]
2025-12-21 fix: Show reboot request response in UI
    Also make response from api more understandable for non-technical users.
    [webserver.py]
2025-12-21 feat: Long press VOL_DOWN button to shutdown/reset device
    [buttons.py]
2025-12-23 fix: webserver: Catch and report IO errors on upload
    [webserver.py]
2025-12-27 feat: Join an existing WiFi network
    Add ssid and passphrase to config to configure the network to join. If
    empty SSID is configured, it will create the "TonberryPicoAP..." network
    in AP mode as before.
    Holding the button 1 during startup will revert to AP mode regardless of
    the current configuration.
    [config.py, main.py]
2025-12-27 feat: Visual feedback on LEDs during startup
    Set the LEDs to a fixed color during bootup to show the different modes:
    - Orange when the device is booting
    - Red when button 0 is held and the device goes to a shell
    - Blue when button 1 is held and the device goes to AP mode instead of
    joining the configured WiFi network
    - Red blinking when the run() method throws an exception for any reason
    [main.py]
2025-12-27 fix: frontend: Replace generic 'Device admin' title
2025-12-27 feat: Add names to playlists
    Fixes #63.
    [playlistdb.py, webserver.py]
2025-12-27 fix: allow 'reboot' to application when on on battery
    Having to press the power button again to wake up the device is less
    annoying to the user than not being able to apply settings when the
    device is on battery.
    [webserver.py]
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2025-12-27 fix: webserver: file uploading
    - Fix upload of files <= Request.max_body_length
    File uploads smaller than the limit were not given to the handler as a
    stream by microdot, instead the content is directly stored in the
    request.body.
    - Refactor stream to file copy into a helper method
    - Increase the copy buffer size to 16k
    - Call app.reset_idle_timeout() periodically during file uploads to
    avoid the device turning off when uploading large files while on
    battery.
    [webserver.py]
2025-12-27 fix: button 0 to shutdown device when in error state
    [main.py]
2026-01-06 fix: Remove directory based db creation
    Previously, if no tonberry.db existed on the SD card, the database was
    initialized with a playlist for each directory containing mp3 files,
    with the tag serial number matching the directory name. This was used
    during development before the web UI to edit the playlist db existed.
    It is no longer necessary, and confusing to the user when unusable
    playlists are created when albums are preloaded onto the SD card before
    putting it in the tonberry device.
    [main.py]
2026-01-06 fix[player]: Don't latch tag if no playlist exists
    When the device is in 'tagstartstop' tag mode, and the user presents a
    new tag to get the serial number and create a playlist using the web UI,
    the playerapp still remembered the tag as the currently playing tag even
    though no playlist was found and no playback is running. After the user
    saves the playlist in the UI and puts the tag on the device again, they
    expect the playback to start with the new playlist. Instead, nothing
    happens, because this is counted as the 'stop' event of the tagstartstop
    mode. The user would have to remove the tag and present it again (after
    waiting for the tagtimeout) to play the new playlist.
    Fix this unexpected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
    [app.py]
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2026-01-13 fix: Reduce file upload chunk size to 4k
    After seeing occasional memory allocation failures on file upload,
    reduce chunk size to 4k again.
    [webserver.py]
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2026-01-27 fix: webserver: catch and report exceptions from open and mkdir, too
    [webserver.py]
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2026-05-05 Fix WiFi setup when passphrase is not set
    When the WiFi passphrase is not set (for example during initial
    provisioning with a default configuration), the security parameter
    passed to setup_wifi needs to be set to SEC_OPEN. Otherwise, the WiFi
    driver will create a secure WLAN with an empty passphrase, which is
    invalid and cannot be connected to.
    [main.py]
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2026-05-21 fix(audiocore): Support mono MP3s and those with != 1152 samples/frame
    Support decoding mono mp3s by duplicating the mono channel to L and R
    channels.
    Support decoding mp3s that have a different samples per frame value by
    extending mp3_decode to return the number of samples it has written to
    the PCM buffer. The i2s driver is extended to take the number of valid
    samples as an argument to i2s_commit_buf and will adjust the length of
    the DMA transfer accordingly.
    Fixes #77.
    [mp3.c]
2026-05-21 fix(mp3player): Skip ID3 tags at start of track
    Some data in ID3 tags, especially embedded cover art, can confuse the
    simple scan for an MP3 sync word that is performed by the actual MP3
    decoder and causes some files to fail to play.
    Avoid this by detecting ID3 headers at the beginning of tracks and
    skipping the ID3 data before passing the rest of the file to the MP3
    decoder.
    Fixes #76.
    [mp3player.py]
2026-05-25 feat(mechanical): Add test-rig for v1.2 PCB and button board
    [test-rig-pcbv1.2.FCStd]
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2026-06-07 hardware: add button board PCB files
    [tonberry-pico-buttons.kicad_pcb, tonberry-pico-buttons.kicad_sch]
2026-06-16 cleanup: Remove breadboard configuration
    Remove the breadboard board manifest and board config. The breadboard
    firmware build is removed by removing the manifest.
    No instances of the original breadboard setup are still in existence. It
    drives up the build time and may confuse newcomers. If someone needs a
    new breadboard setup, nothing prevents them from wiring it to match the
    Rev.1 pinout.
    [hwconfig.py]
2026-06-16 fix(modules/rp2_sd): Proper SD read/write timeouts
    Wait for SD cards to complete read or write operations with a proper
    timeout (maximum times specified in standard plus a safety
    margin). Replaces the previous logic that 'guesstimated' some timeout
    based on the number of retries.
    [sd_spi.c]
2026-06-16 feat: Add SD multiblock write support; Fix logging
    Add support for CMD25 to write multiple sequential blocks in one go, in
    an attempt to speed up uploads. For some SD cards this has been reported
    to result in significant speed ups.
    Also fix logging from SD driver to be visible even when running under
    micropython.
    [main.c, module.c, sd_spi.c]
2026-08-03 docu: fixed rc522 pin name
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2026-08-18 fix: typo, info about end-of-charge voltage
2026-08-18 feat(playlist): Don't automatically wrap playlist
    Make playlist logic slightly more sane:
    * When reaching the end of the playlist, getNextPath returns None. It
    will continue to return None as long as the playlist position is not
    changed by other means.
    * A new restart() method resets the playlist position to the first
    track.
    * Calling getPrevPath when the playlist has reached the end will return
    the last track of the playlist.
    [playlistdb.py]
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

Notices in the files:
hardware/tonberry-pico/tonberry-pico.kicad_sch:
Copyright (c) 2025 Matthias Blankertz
